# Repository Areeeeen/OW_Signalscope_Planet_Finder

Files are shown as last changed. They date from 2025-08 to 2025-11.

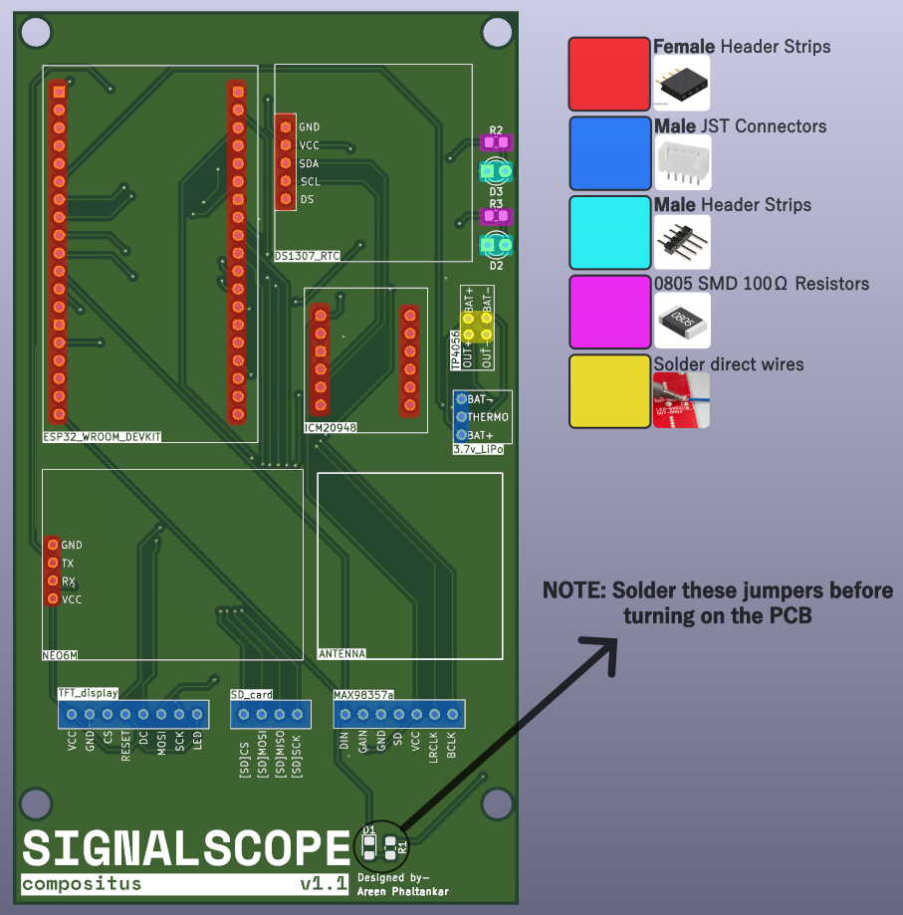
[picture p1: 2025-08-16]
PCB design files/Compositus/v1.1/PCB_assembly_instructions.png

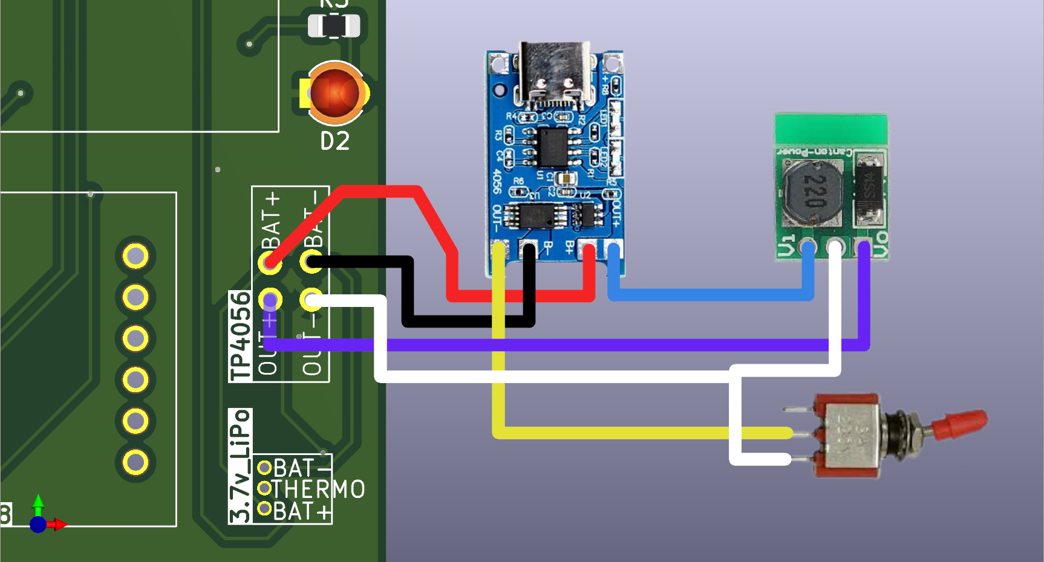
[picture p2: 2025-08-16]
PCB design files/Compositus/general POWER CIRCUIT schematic.png

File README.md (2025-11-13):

# OW_Signalscope_Planet_Finder
An open-source, portable, Outer Wilds 'SignalScope' inspired Planet Finder, based on the ESP32-WROOM (38 pin) microcontroller

refer to this instructables link for instructions on assembly - https://www.instructables.com/Outer-Wilds-Signalscope-Inspired-Planet-Finder/

poster1
display

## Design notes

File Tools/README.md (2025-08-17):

these are Arduino codes which will help in building the signalscope

**i2c_Scanner** - to check which I2C address each I2C module uses, in the case that you use different components than i did

**ICM20948_Calibration** - to find magnetometer and accelerometer offsets of the IMU. (use code when ESP32 and all other compoenents are in their respective places on the device)

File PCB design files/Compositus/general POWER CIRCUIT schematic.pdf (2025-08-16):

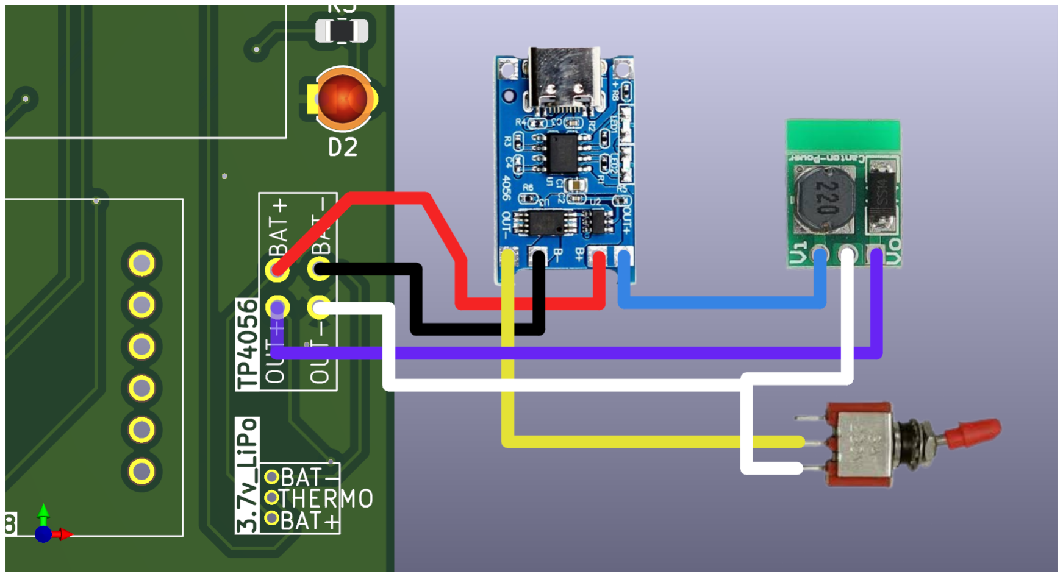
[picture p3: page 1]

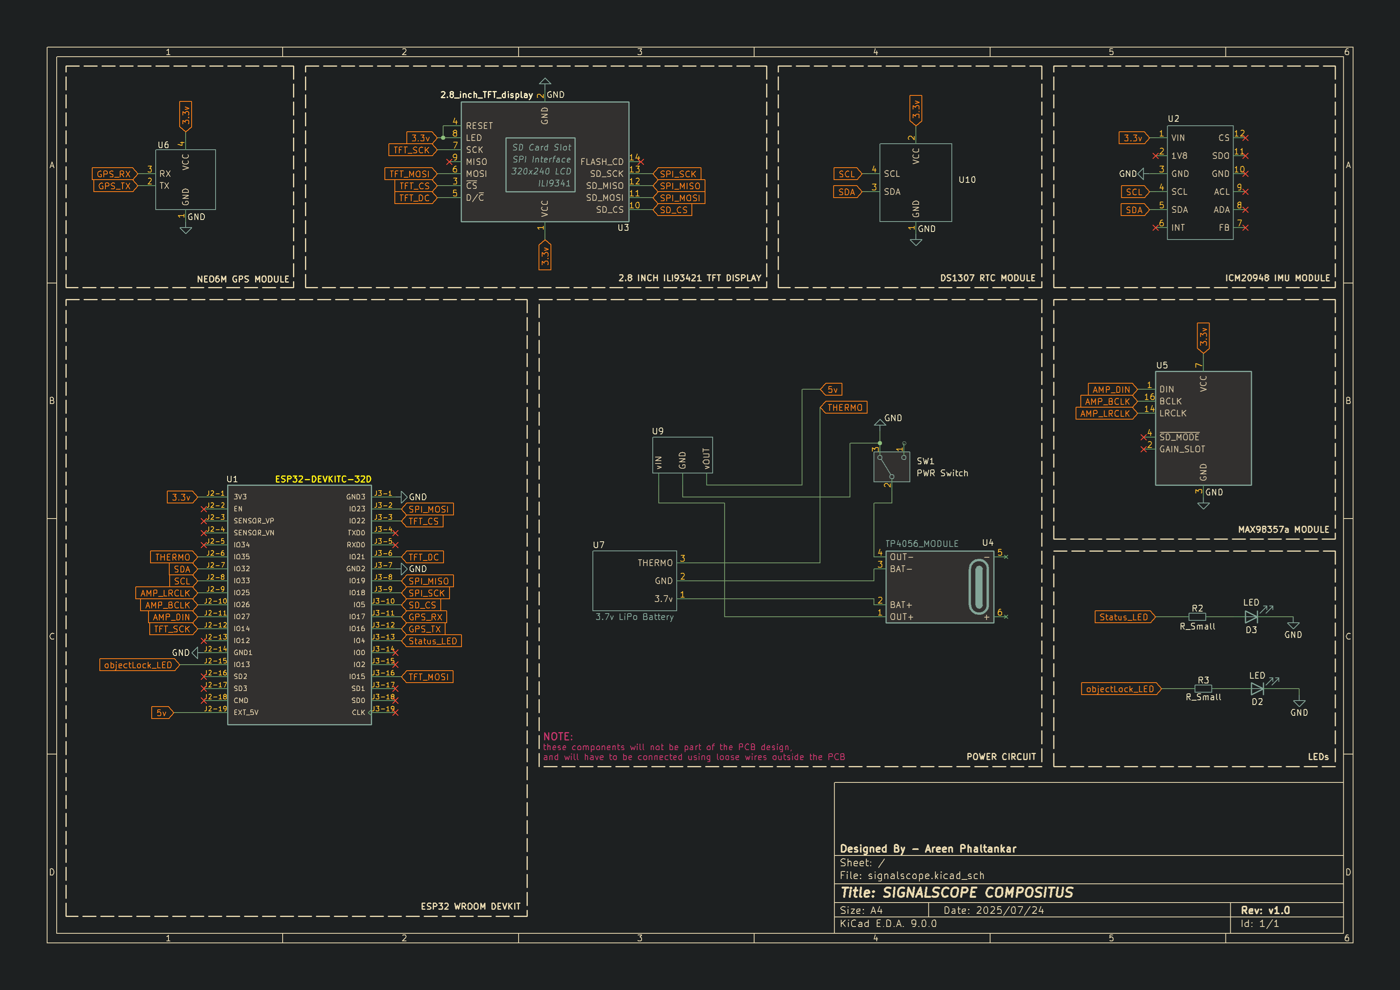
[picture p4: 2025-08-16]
PCB design files/Compositus/v1.1/schematic.png

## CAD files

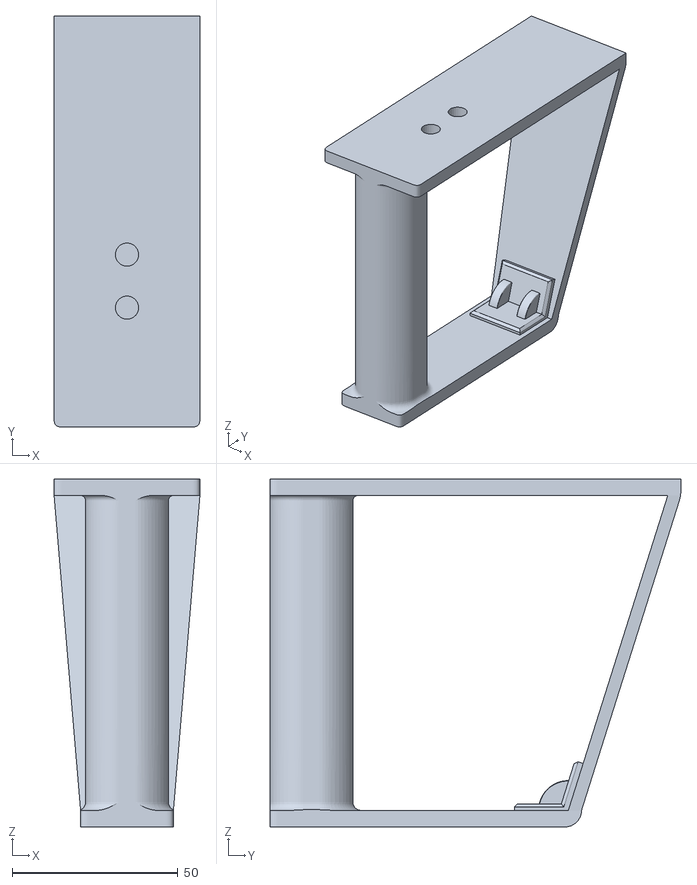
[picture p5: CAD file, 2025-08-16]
3D model files/Handle/Handle_STL_v1.0.stl
44.0 x 124.0 x 105.0

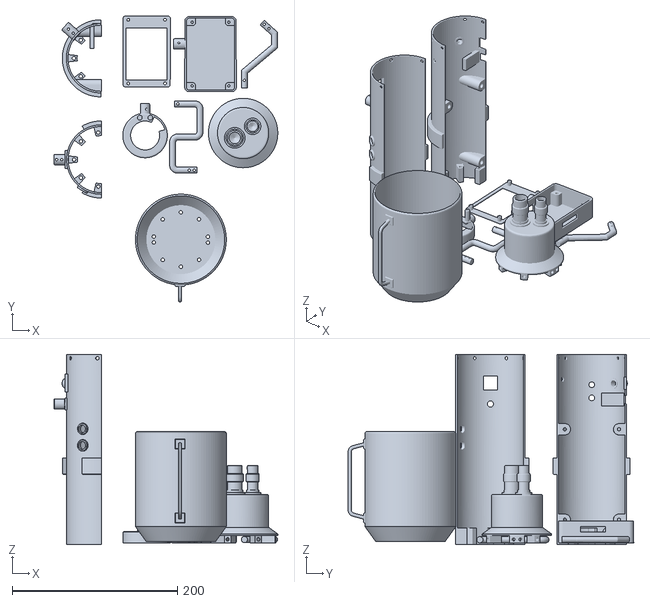
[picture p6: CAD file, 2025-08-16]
3D model files/v1.0/Signalscope_STL_v1.0.stl
270.7 x 346.1 x 230.0

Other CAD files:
3D model files/Handle/Handle_FUSION_v1.0.f3d

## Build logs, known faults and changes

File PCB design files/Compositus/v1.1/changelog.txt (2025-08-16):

- changed pitch and hole diameter of battery connector footprint to 2.54 and 1.5 respectively
- so that it can be easily used with 2.54 pitch JST connector

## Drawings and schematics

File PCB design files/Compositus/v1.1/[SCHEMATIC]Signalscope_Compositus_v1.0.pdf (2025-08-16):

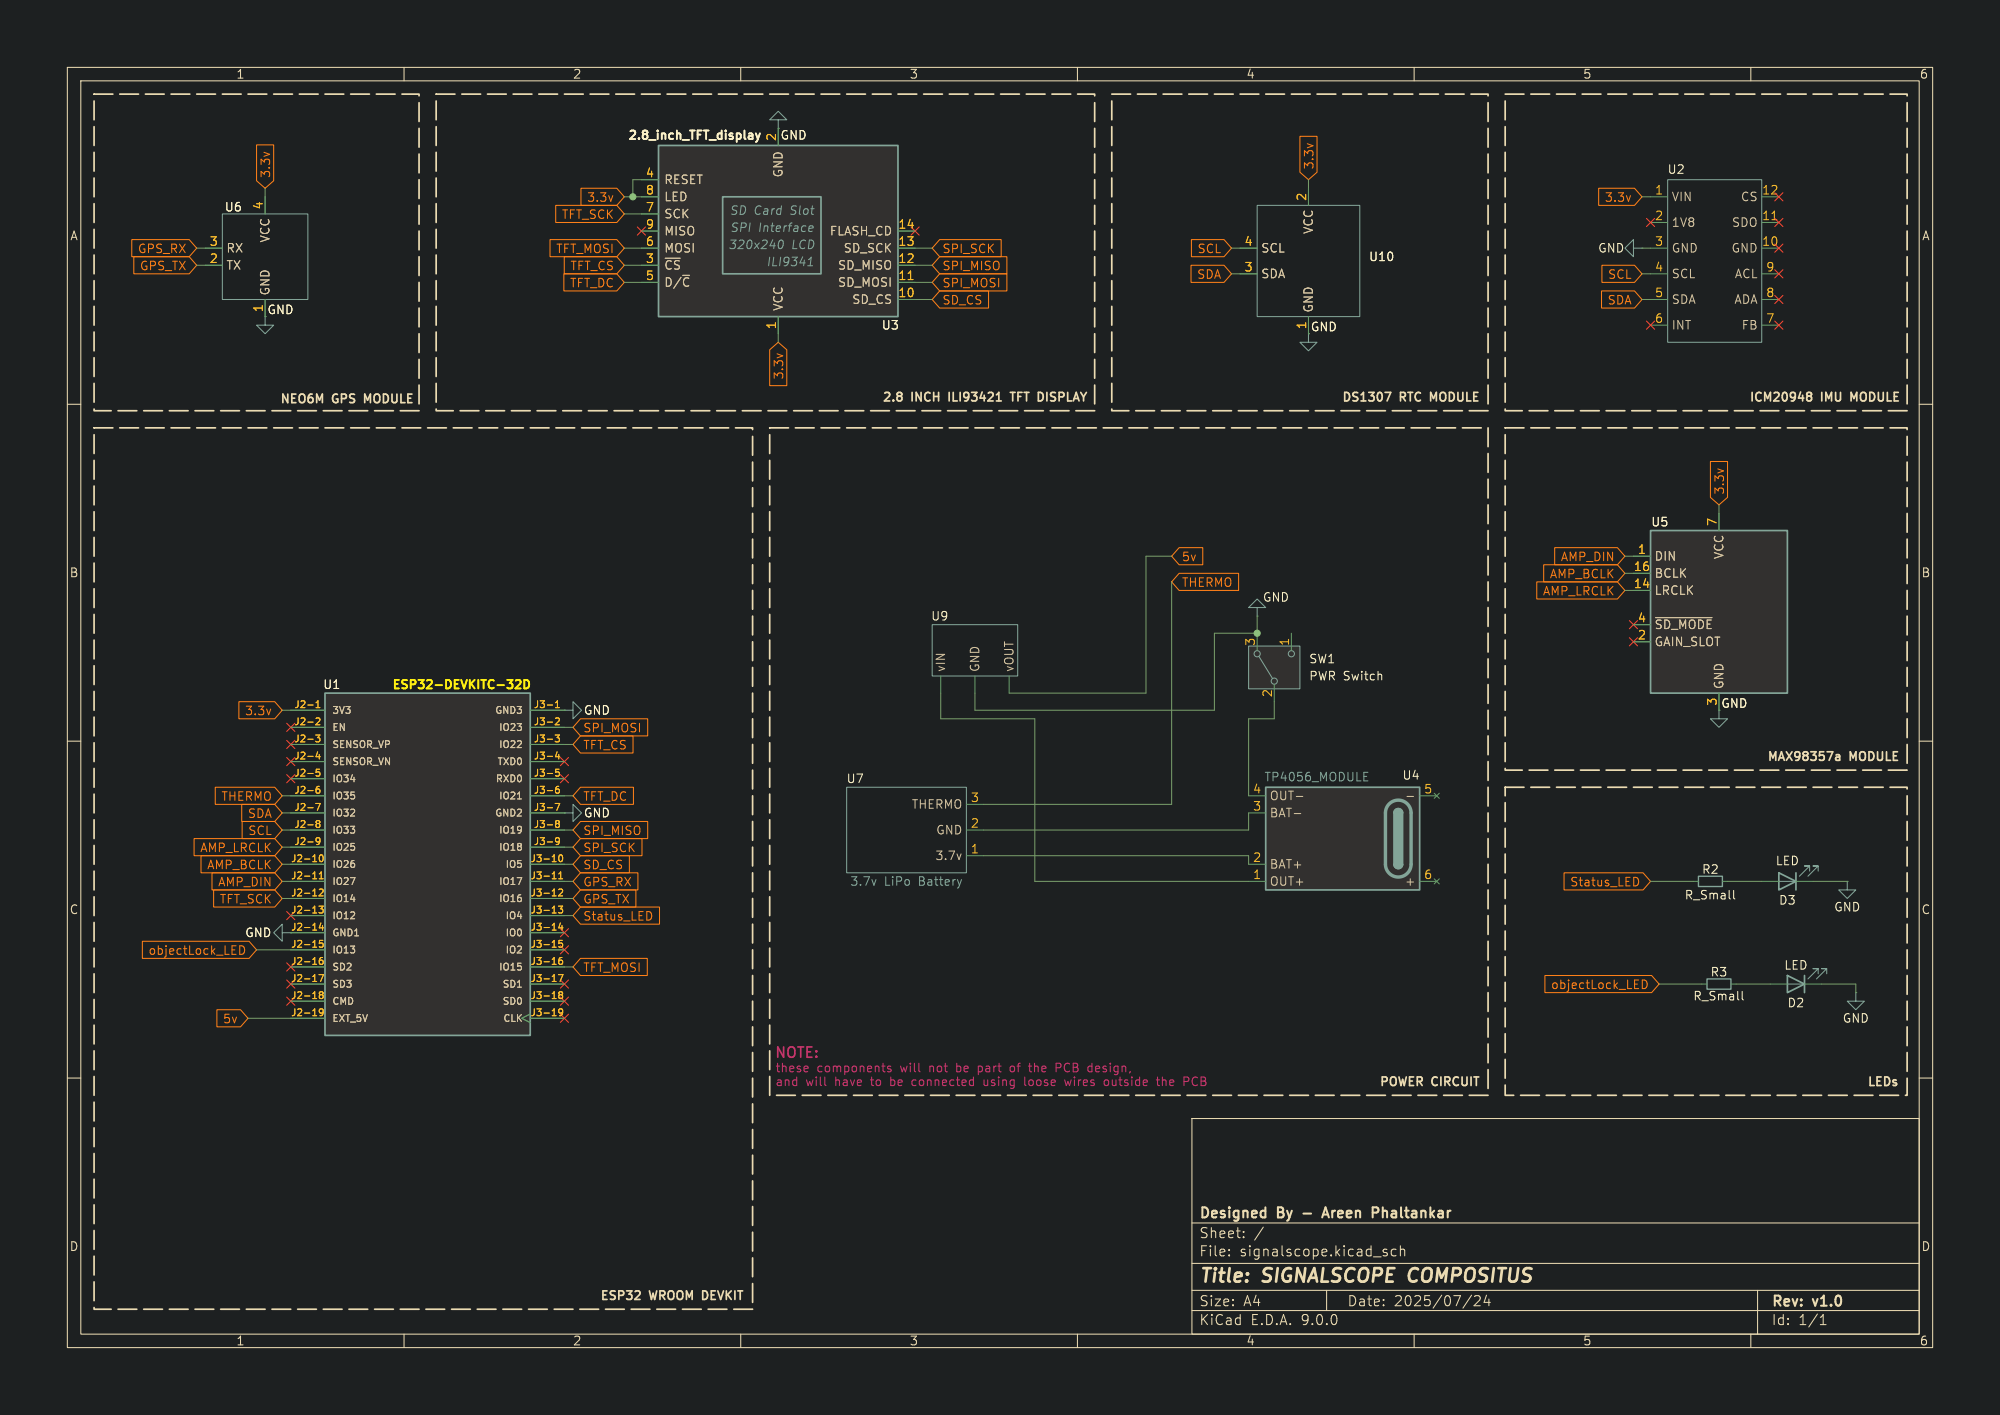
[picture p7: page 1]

2 D/~{C} 5 ~{CS} 3 MOSI 6 MISO 9 SCK 7

3.7v LiPo Battery THERMO 3 GND 2

Id: 1/1 Title: SIGNALSCOPE COMPOSITUS

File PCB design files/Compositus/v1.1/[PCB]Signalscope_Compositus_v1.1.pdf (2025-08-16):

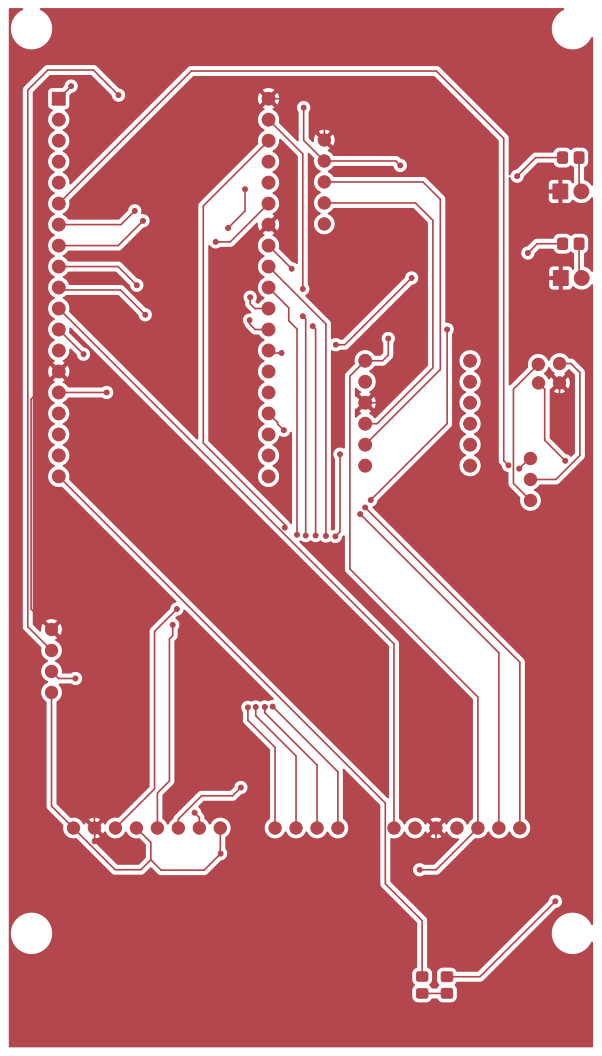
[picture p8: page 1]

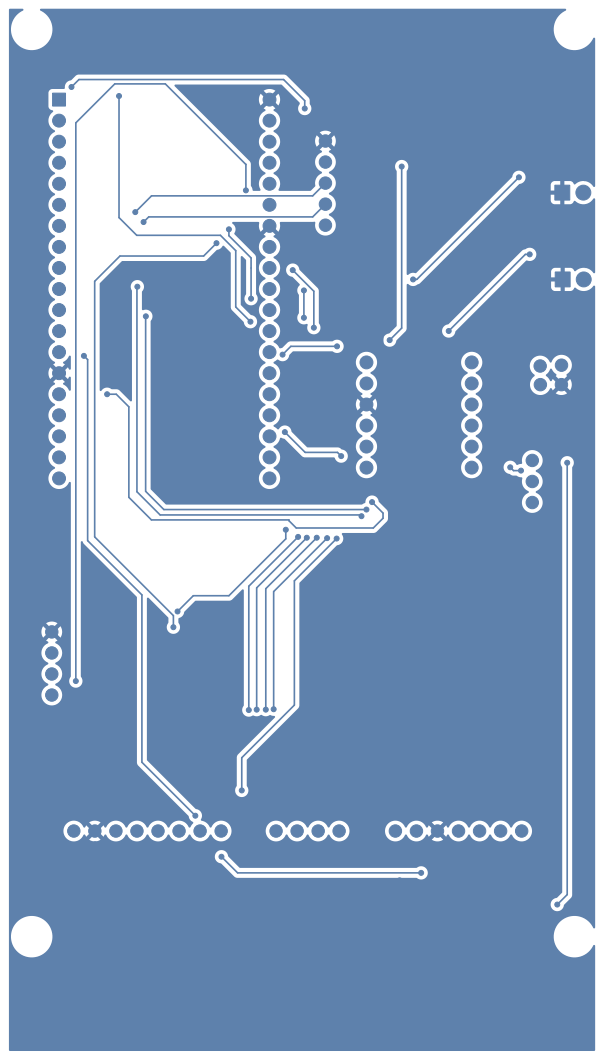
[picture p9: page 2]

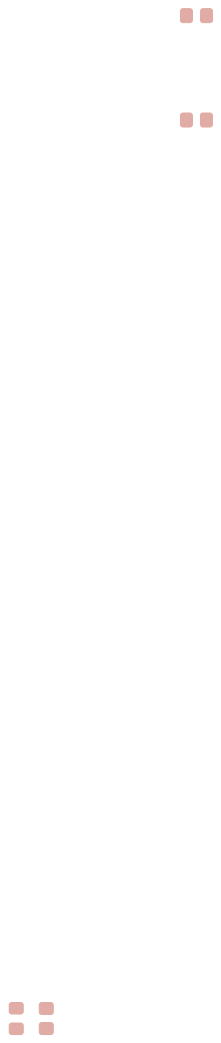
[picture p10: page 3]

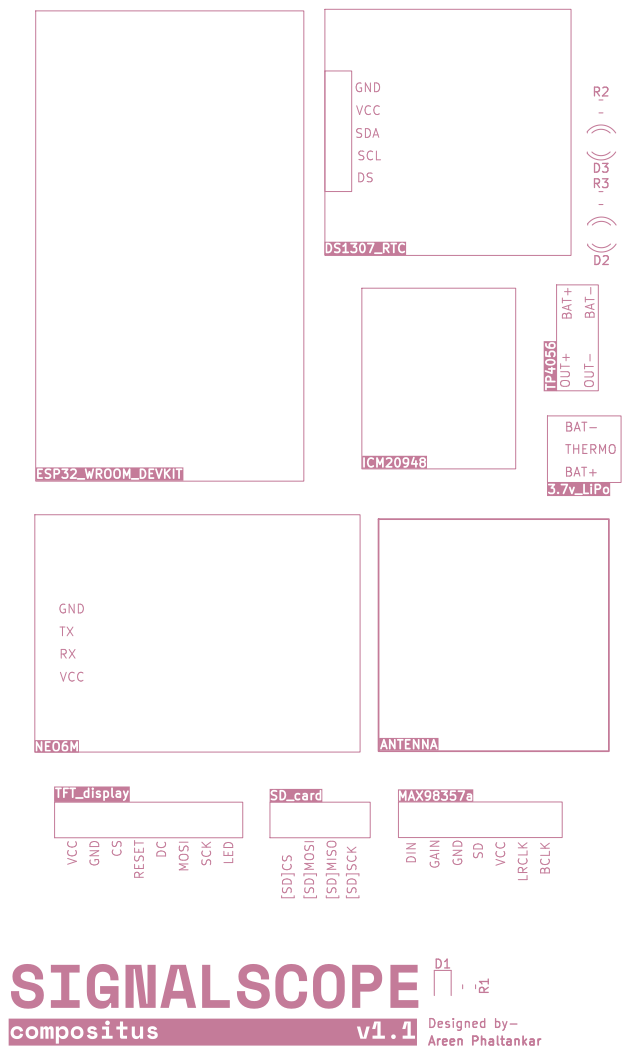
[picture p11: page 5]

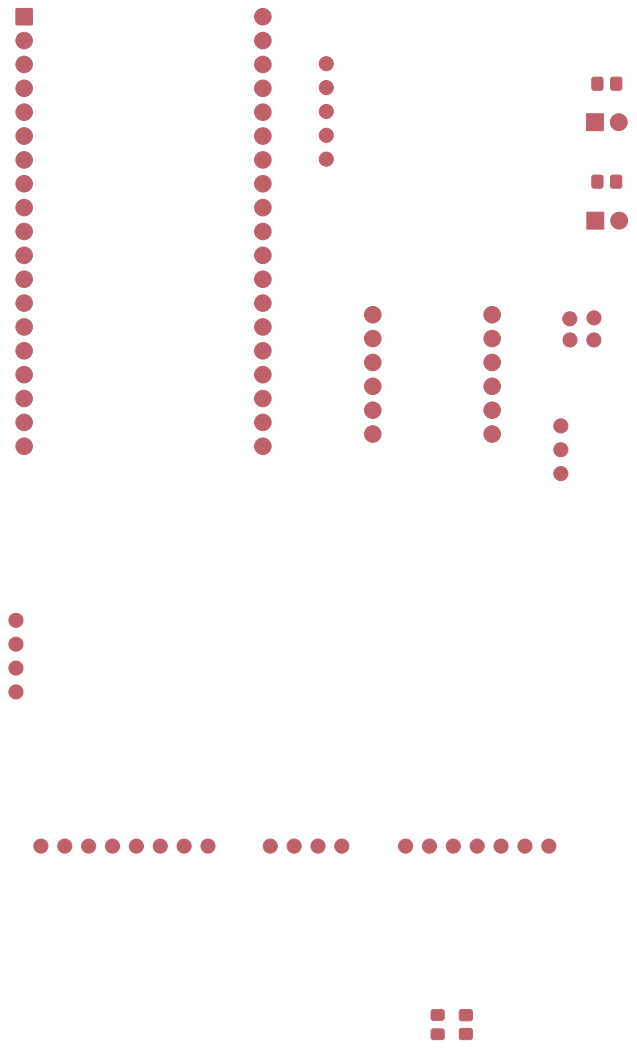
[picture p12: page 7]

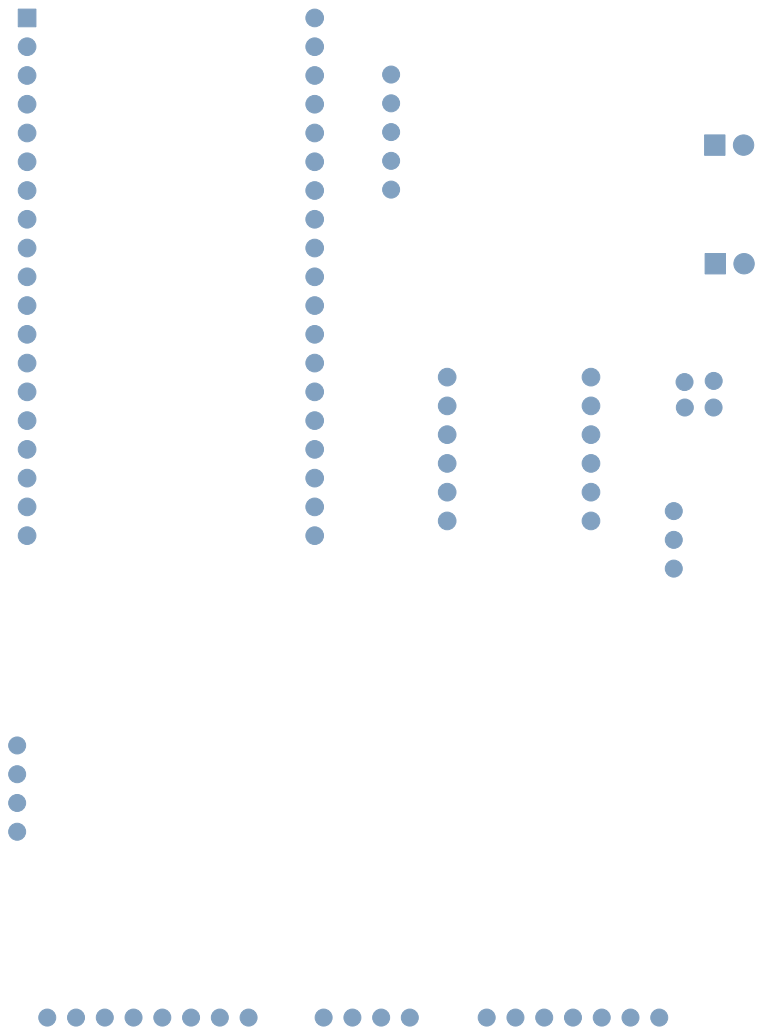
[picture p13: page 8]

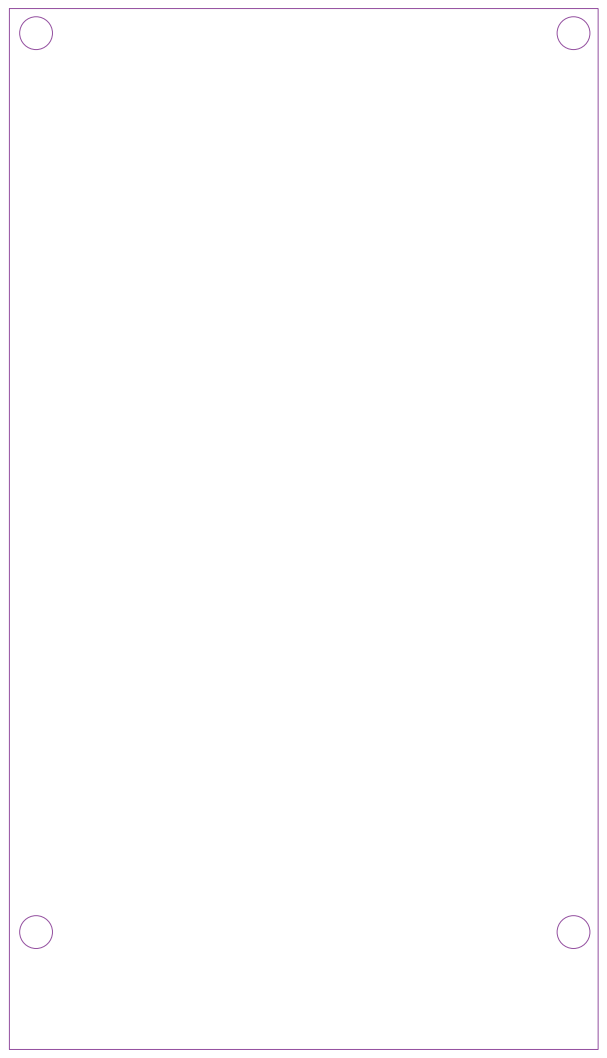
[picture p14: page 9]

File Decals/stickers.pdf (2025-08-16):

# WILDS [1]

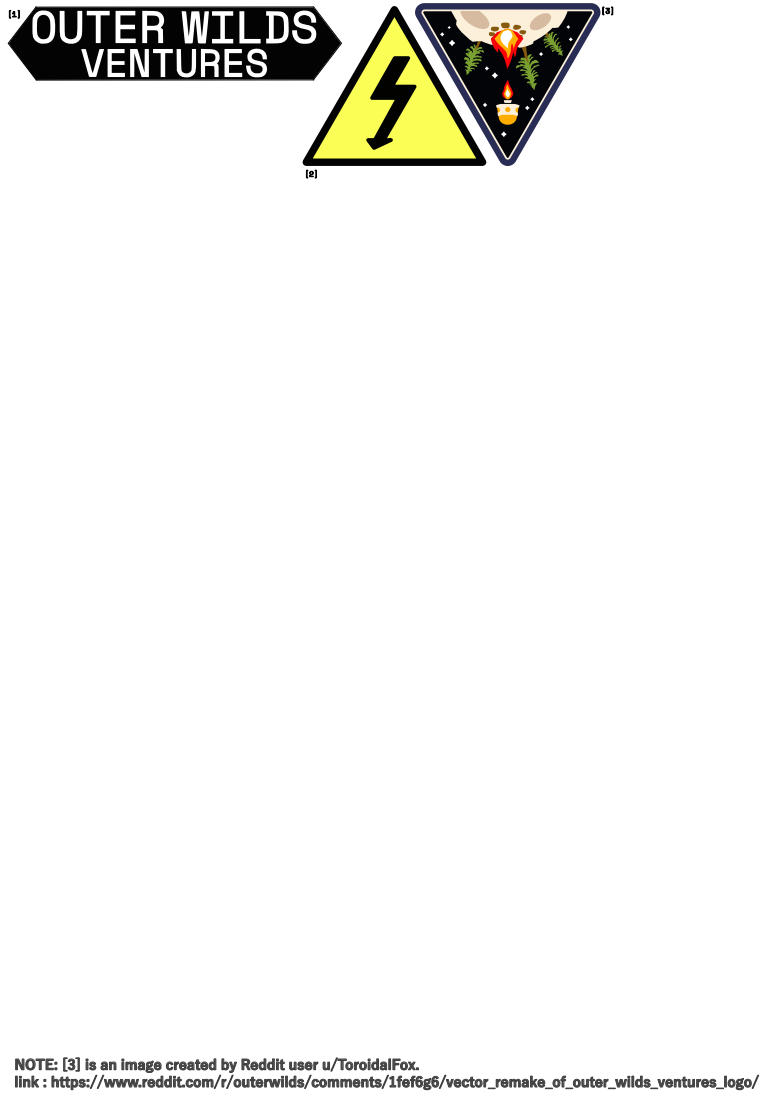
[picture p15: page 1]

NOTE: [3] is an image created by Reddit user u/ToroidalFox.
link : https://www.reddit.com/r/outerwilds/comments/1fef6g6/vector̲remake̲of̲outer̲wilds̲ventures̲logo/

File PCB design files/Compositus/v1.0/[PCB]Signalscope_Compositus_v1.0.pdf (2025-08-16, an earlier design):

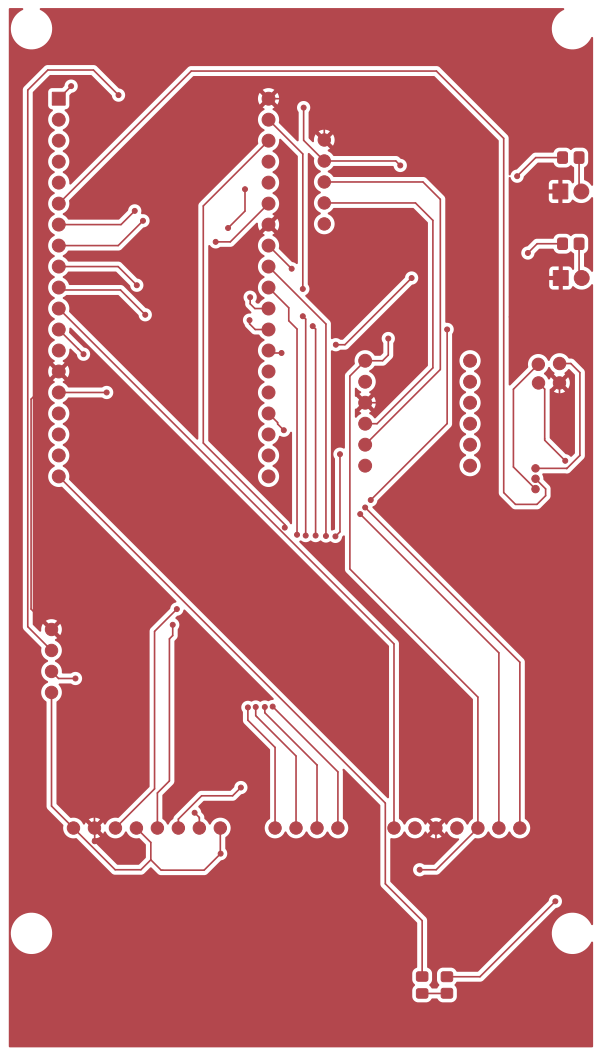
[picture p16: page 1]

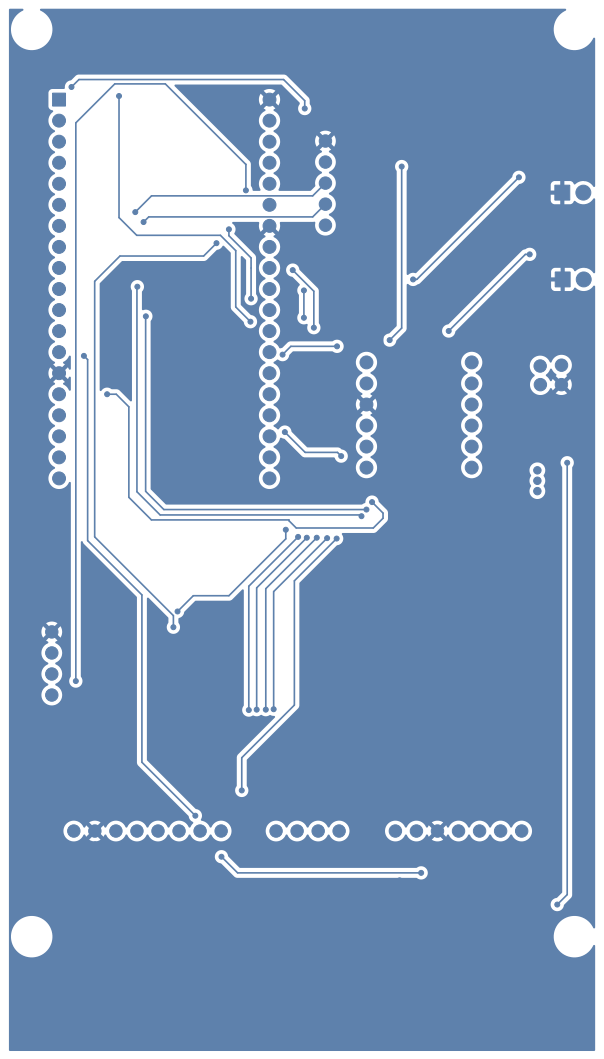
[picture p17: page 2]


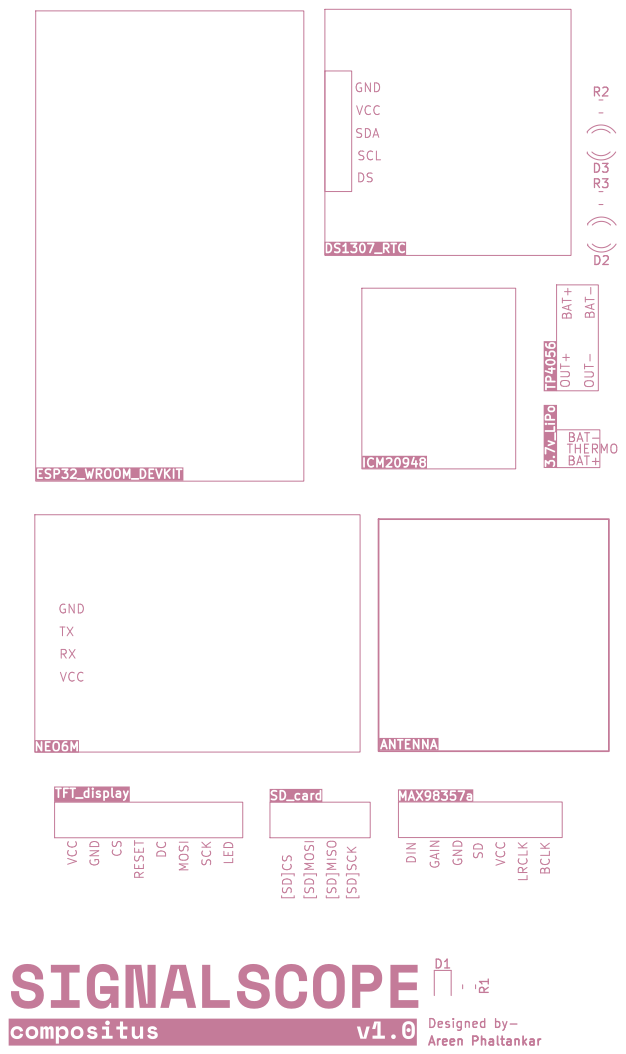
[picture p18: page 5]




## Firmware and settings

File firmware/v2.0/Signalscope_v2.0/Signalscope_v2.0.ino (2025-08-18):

// Signalscope_v2.0
// Made By - Areen Phaltankar

#include <Wire.h>
#include <ICM20948_WE.h>
#include <RTClib.h>
#include <TFT_eSPI.h>
#include <FS.h>
#include <WiFi.h>
#include <HTTPClient.h>
#include <ArduinoJson.h>
#include <AudioFileSourceSD.h>
#include <AudioGeneratorWAV.h>
#include <AudioOutputI2S.h>
#include <AudioFileSourceBuffer.h>
#include <TinyGPS++.h>
#include <SPI.h>
#include <SD.h>
#include <PNGdec.h>

#define ASTRONOMY_ENGINE_WHOLE_SECOND   // ESP32: use 1-second resolution
#include "astronomy.h"                  // keep astronomy.c beside the sketch, compiled as a separate file
#include "loading.h" // The loading screen image data in flash array

const char* ssid = "YOUR_WIFI_NAME";
const char* password = "YOUR_WIFI_PASSWORD";

double latitude = //YOUR_LONGITUDE;
double longitude = //YOUR_LONGITUDE;

astro_time_t astroTime;                 // current time for Astronomy Engine
astro_observer_t observer = { 0, 0, 0}; // lat, lon, elevation meters (set after GPS / fallback)

struct Planet {              // Define a struct to hold planet data
  const char* name;
  const char* music;
  float dec;
  float RA;
  float Az;                  // data will be added by the code for the Azimuth and Altitude
  float Alt;
  float offset;
  float distanceAU;
};

Planet planets[] = {                                    
  {"Mercury", "/Mercury.wav"},
  {"Venus",   "/Venus.wav"},
  {"Mars",    "/Mars.wav"},
  {"Jupiter", "/Jupiter.wav"},         
  {"Saturn",  "/Saturn.wav"},
  {"Uranus",  "/Uranus.wav"},
  {"Neptune", "/Neptune.wav"}
};

PNG png;
#define MAX_IMAGE_WIDTH 240
int16_t xpos = 0;
int16_t ypos = 0;

TaskHandle_t TaskCore0Handle;
TaskHandle_t AudioTaskHandle;

ICM20948_WE myIMU = ICM20948_WE(0x69);
const float magX_offset = -21.902;
const float magY_offset = -12.483;
const float magZ_offset = 27.059;
volatile float altitude_deg;
volatile float azimuth_deg;
float closestOffset;
String closestPlanet;
float closestDistance;
volatile bool imuDataReady = false;

RTC_DS1307 rtc;
#define IST_OFFSET_SECONDS 19800
#define NTP_SERVER "pool.ntp.org"

bool wifiConnected = false;

HardwareSerial gpsSerial(2); // Serial2 for GPS
TinyGPSPlus gps;

TFT_eSPI tft = TFT_eSPI();
TFT_eSprite sprite = TFT_eSprite(&tft);  // Framebuffer sprite
uint8_t radius       = 60; // Arc outer radius
uint8_t thickness    = 4;
uint8_t inner_radius = radius - thickness;
uint16_t LEFTstart_angle = 0;
uint16_t LEFTend_angle   = 180;
uint16_t RIGHTstart_angle = 180;
uint16_t RIGHTend_angle   = 0;
bool arc_end = true;
int centerX = 120;
int centerY = 160;

unsigned long lastUpdateTime = 0;
const unsigned long updateInterval = 5000;

#define GPS_RX 16
#define GPS_TX 17
#define GPS_BAUD 9600

#define TFT_MOSI 15
#define TFT_SCLK 14
#define TFT_CS   22
#define TFT_DC   21
#define TFT_RST  -1

SPIClass mySPI(VSPI);
#define SD_CS    5
#define SD_SCK   18
#define SD_MISO  19
#define SD_MOSI  23

#define I2S_BCLK 26
#define I2S_LRCK 25
#define I2S_DOUT 27

#define LED_PWR 4
#define LED_LOCKOn 13

AudioGeneratorWAV *wav = nullptr;
AudioFileSourceSD *file = nullptr;
AudioOutputI2S *out = nullptr;
AudioFileSourceBuffer *buff = nullptr;

#define AA_FONT_SMALL "NotoSansBold15"
#define AA_FONT_LARGE "NotoSansBold36"

void pngDraw(PNGDRAW *pDraw) {
  uint16_t lineBuffer[MAX_IMAGE_WIDTH];
  png.getLineAsRGB565(pDraw, lineBuffer, PNG_RGB565_BIG_ENDIAN, 0xffffffff);
  tft.pushImage(xpos, ypos + pDraw->y, pDraw->iWidth, 1, lineBuffer);
}

String currentPlaying = "";
const float offsetThreshold = 20.0;

void handlePlanetAudio() {
  // If offset is too large, stop audio if running
  if (closestOffset > offsetThreshold) {
    if (wav && wav->isRunning()) {
      wav->stop();
      currentPlaying = "";
    }
    return;
  }

  // Find the matching planet to get the file path
  const char* filepath = nullptr;
  for (int i = 0; i < 7; i++) {
    if (String(planets[i].name) == closestPlanet) {
      filepath = planets[i].music;
      break;
    }
  }

  if (filepath == nullptr) return; // No matching file

  // Avoid restarting same track
  if (currentPlaying == String(filepath) && wav && wav->isRunning()) {
    // Update volume based on offset
    float vol = 1.0 - (closestOffset / offsetThreshold);
    vol = constrain(vol, 0.0, 1.0);
    if (out) out->SetGain(vol);
    return;
  }

  // Stop any current audio
  if (wav && wav->isRunning()) wav->stop();
  if (file) delete file;
  if (buff) delete buff;
  if (wav) delete wav;
  if (out) delete out;

  // Prepare new file and playback
  file = new AudioFileSourceSD(filepath);
  buff = new AudioFileSourceBuffer(file, 8192);
  out = new AudioOutputI2S();
  out->SetPinout(26, 25, 27);  // Replace with your actual I2S pins

  // Set initial volume based on offset
  float volume = 1.0 - (closestOffset / offsetThreshold);
  volume = constrain(volume, 0.0, 1.0);
  out->SetGain(volume);

  wav = new AudioGeneratorWAV();
  if (!wav->begin(buff, out)) {
    Serial.println("Failed to play audio.");
    currentPlaying = "";
  } else {
    Serial.print("Now playing: ");
    Serial.println(filepath);
    currentPlaying = String(filepath);
  }
}

void updateUserLocation() {
  Serial.print("Latitude: ");
  Serial.println(gps.location.lat(), 6);
  latitude = gps.location.lat();

  Serial.print("Longitude: ");
  Serial.println(gps.location.lng(), 6);
  longitude = gps.location.lng();
}

void TaskCore0(void *pvParameters) {
  while (true) {
    xyzFloat gValue;
    xyzFloat angle;
    xyzFloat magValue;

    myIMU.readSensor();
    myIMU.getGValues(&gValue);
    myIMU.getMagValues(&magValue);
    myIMU.getAngles(&angle);

    magValue.x -= magX_offset;
    magValue.y -= magY_offset;
    magValue.z -= magZ_offset;

    // Normalize accelerometer vector
    float normAcc = sqrt(gValue.x * gValue.x + gValue.y * gValue.y + gValue.z * gValue.z);
    float ax = gValue.x / normAcc;
    float ay = gValue.y / normAcc;
    float az = gValue.z / normAcc;

    // Compute pitch (altitude) and roll
    float pitch = atan2(-ax, sqrt(ay * ay + az * az)); // radians
    float roll  = atan2(ay, az); // radians

    // Normalize magnetometer vector
    float normMag = sqrt(magValue.x * magValue.x + magValue.y * magValue.y + magValue.z * magValue.z);
    float mx = magValue.x / normMag;
    float my = magValue.y / normMag;
    float mz = magValue.z / normMag;

    // Tilt compensation for magnetometer
    float mx2 = mx * cos(pitch) + mz * sin(pitch);
    float my2 = mx * sin(roll) * sin(pitch) + my * cos(roll) - mz * sin(roll) * cos(pitch);

    // Azimuth (heading), in radians
    float azimuth = atan2(-my2, mx2);
    float azimuth_deg_local = (azimuth * 180.0 / PI); 
    if (azimuth_deg_local < 0) azimuth_deg += 360.0; // Normalize to 0-360

    float altitude_deg_local = -(pitch * 180.0 / PI);

    azimuth_deg = azimuth_deg_local;
    altitude_deg = altitude_deg_local;
    imuDataReady = true;

    vTaskDelay(50 / portTICK_PERIOD_MS);  // run at ~20Hz
  }
}

void TaskAudio(void *pvParameters) {
  while (true) {
    handlePlanetAudio();  // Adjust volume or switch track if needed

    if (wav && wav->isRunning()) {
      wav->loop();  // Keep audio playing
    } else {
      vTaskDelay(10 / portTICK_PERIOD_MS);  // Light sleep
    }
  }
}

int hack;

void findOffsets() {
  for (int i = 0; i < 7; i++) {
  Planet& target = planets[i];
  float az_rad = azimuth_deg * PI / 180.0;
  float alt_rad = altitude_deg * PI / 180.0;

  // Convert to 3D unit vector
  float dx = cos(alt_rad) * sin(az_rad);
  float dy = cos(alt_rad) * cos(az_rad);
  float dz = sin(alt_rad);

  // Convert planet azimuth & altitude to radians
  float p_az_rad = target.Az * PI / 180.0;
  float p_alt_rad = target.Alt * PI / 180.0;

  // Convert to 3D unit vector
  float pdx = cos(p_alt_rad) * sin(p_az_rad);
  float pdy = cos(p_alt_rad) * cos(p_az_rad);
  float pdz = sin(p_alt_rad);

  // Dot product
  float dot = dx*pdx + dy*pdy + dz*pdz;
  dot = constrain(dot, -1.0, 1.0); // Prevent acos domain errors

  float angleBetween = acos(dot) * 180.0 / PI;

  target.offset = angleBetween;
  }
  //Serial.printf("Running on core: %d\n", xPortGetCoreID());
}

void closestBody() {
  closestOffset = planets[0].offset;
  for (int i = 1; i < 7; i++) {
    if (planets[i].offset < closestOffset) {
      closestOffset = planets[i].offset;
      closestPlanet = planets[i].name;
      closestDistance = planets[i].distanceAU;
    }
  }
}
// Sync DS1307 from NTP if Wi-Fi is up (else leave RTC as-is)
void updateTime() {
  if (WiFi.status() == WL_CONNECTED) {
    configTime(0, 0, "pool.ntp.org");
    delay(1500);

    struct tm gmt;
    if (getLocalTime(&gmt)) {
      rtc.adjust(DateTime(gmt.tm_year + 1900, gmt.tm_mon + 1, gmt.tm_mday,
                          gmt.tm_hour, gmt.tm_min, gmt.tm_sec));
      Serial.println("RTC updated from NTP.");
    } else {
      Serial.println("NTP time not available; keeping RTC time.");
    }
  } else {
    Serial.println("Wi-Fi down; using RTC time.");
  }
}

// Read DS1307 and build astro_time_t
void refreshDateandTime() {
  DateTime now = rtc.now();
  astroTime = Astronomy_MakeTime(now.year(), now.month(), now.day(),
                                 now.hour(), now.minute(), (double)now.second());
  // (optional) show the time you’re feeding AE:
  astro_utc_t utc = Astronomy_UtcFromTime(astroTime);
  Serial.printf("UTC: %04d-%02d-%02d %02d:%02d:%02d\n",
                utc.year, utc.month, utc.day, utc.hour, utc.minute, (int)utc.second);
}

// map Planet.name -> astro_body_t
static bool nameToBody(const char* n, astro_body_t &body) {
  if      (!strcmp(n,"Mercury")) body = BODY_MERCURY;
  else if (!strcmp(n,"Venus"))   body = BODY_VENUS;
  else if (!strcmp(n,"Mars"))    body = BODY_MARS;
  else if (!strcmp(n,"Jupiter")) body = BODY_JUPITER;
  else if (!strcmp(n,"Saturn"))  body = BODY_SATURN;
  else if (!strcmp(n,"Uranus"))  body = BODY_URANUS;
  else if (!strcmp(n,"Neptune")) body = BODY_NEPTUNE;
  else return false;
  return true;
}

// Updates a single planet's RA/Dec, Az/Alt, and Earth distance (AU)
void refreshAzAlt(Planet& p) {
  astro_body_t body;
  if (!nameToBody(p.name, body)) return;

  // apparent RA/Dec at observer’s location (equator-of-date, with aberration)
  astro_equatorial_t equ = Astronomy_Equator(body, &astroTime, observer,
                                             EQUATOR_OF_DATE, ABERRATION);
  // store RA/Dec for your struct (degrees)
  p.RA  = equ.ra * 15.0;                // RA hours -> degrees
  p.dec = equ.dec;

  // convert to horizon (Az/Alt) for this observer
  astro_horizon_t horiz = Astronomy_Horizon(&astroTime, observer,
                                            equ.ra, equ.dec, REFRACTION_NORMAL);
  p.Az  = horiz.azimuth;
  p.Alt = horiz.altitude;

  // geocentric distance in AU: vector(body) - vector(Earth) in heliocentric coords
  astro_vector_t vPlanet = Astronomy_HelioVector(body, astroTime);       // by value
  astro_vector_t vEarth  = Astronomy_HelioVector(BODY_EARTH, astroTime); // by value
  double dx = vPlanet.x - vEarth.x;
  double dy = vPlanet.y - vEarth.y;
  double dz = vPlanet.z - vEarth.z;
  p.distanceAU = sqrt(dx*dx + dy*dy + dz*dz);

  // debug print
  Serial.printf("%s  RA: %.3f°  Dec: %.3f°  Az: %.3f°  Alt: %.3f°  Dist: %.3f AU\n",
                p.name, p.RA, p.dec, p.Az, p.Alt, p.distanceAU);
}

// refresh all planets in your array
void refreshPlanetsData() {
  for (int i = 0; i < (int)(sizeof(planets)/sizeof(planets[0])); ++i) {
    refreshAzAlt(planets[i]);
  }
}


void updateDisplay() {
  sprite.fillSprite(TFT_BLACK);
  sprite.setTextFont(4);
  tft.loadFont(AA_FONT_SMALL);
  sprite.loadFont(AA_FONT_SMALL);
  sprite.setTextColor(TFT_WHITE, TFT_BLACK); 
  sprite.drawString("Source:", 82, 220);
  sprite.drawString("Distance:", 68, 255);

  if (closestOffset <= 4) {
    sprite.drawSmoothArc(centerX, 100, radius, inner_radius, LEFTstart_angle, LEFTend_angle, TFT_BLUE, TFT_BLACK, arc_end);
    sprite.drawSmoothArc(centerX, 100, radius, inner_radius, RIGHTstart_angle, RIGHTend_angle, TFT_BLUE, TFT_BLACK, arc_end);

    // Draw closest planet name below the semicircles
    sprite.setTextColor(TFT_WHITE, TFT_BLACK);
    sprite.setTextDatum(MC_DATUM);  // Center align
    //sprite.setFreeFont(FSSB18);     // Optional: you can choose other fonts, or comment this if not using free fonts
    sprite.drawString(closestPlanet, 175, 220); // Adjust Y for spacing
    sprite.drawFloat(closestDistance, 2, 160, 255);
    hack = 500;
  } else {
    sprite.drawSmoothArc(centerX - closestOffset, 100, radius, inner_radius, LEFTstart_angle, LEFTend_angle, TFT_GREEN, TFT_BLACK, arc_end);
    sprite.drawSmoothArc(centerX + closestOffset, 100, radius, inner_radius, RIGHTstart_angle, RIGHTend_angle, TFT_GREEN, TFT_BLACK, arc_end);
    hack = 50;
  }

  Serial.println(closestOffset);
  Serial.println(closestPlanet);

  tft.unloadFont();
  sprite.unloadFont();
  sprite.pushSprite(0, 0);
  delay(hack);
}

void setup() {

  pinMode(LED_LOCKOn, OUTPUT);
  pinMode(LED_PWR, OUTPUT);
  digitalWrite(LED_PWR, HIGH); // turn on power LED

  Wire.begin(32, 33); // SDA-32, SCL-33
  Serial.begin(115200);
  gpsSerial.begin(GPS_BAUD, SERIAL_8N1, GPS_RX, GPS_TX);
  
  tft.init();
  tft.setRotation(0);
  int16_t rc = png.openFLASH((uint8_t *)loading, sizeof(loading), pngDraw);
  if (rc == PNG_SUCCESS) {
    Serial.println("Successfully opened png file");
    Serial.printf("image specs: (%d x %d), %d bpp, pixel type: %d\n", 
      png.getWidth(), png.getHeight(), png.getBpp(), png.getPixelType());

    tft.startWrite();
    uint32_t dt = millis();
    png.decode(NULL, 0); // draw it!
    Serial.print(millis() - dt); Serial.println("ms");
    tft.endWrite();
  }

  // Set up sprite the same size as the screen (or smaller, if you want)
  sprite.setColorDepth(8);  // You can use 16 for better color but more memory
  sprite.createSprite(tft.width(), tft.height());

  xTaskCreatePinnedToCore(
    TaskCore0,
    "TaskCore0",
    8192,
    NULL,
    1,
    &TaskCore0Handle,
    1 // Core 0
  );

  xTaskCreatePinnedToCore(
    TaskAudio,
    "TaskAudio",
    4096,
    NULL,
    10,              // High priority (10 is fine for audio)
    &AudioTaskHandle,
    0                // Run on Core 0
  );
  delay(500);

  unsigned long checkGPS = millis();
  while (millis() - checkGPS < 3000) { // Run for 3 seconds
    while (gpsSerial.available() > 0) {
      gps.encode(gpsSerial.read());
    }
  }

  if (gps.location.isValid()) {
    updateUserLocation();
  } else {
    latitude = 18.551464451319365;
    longitude = 73.79048766793403;     // use hard-coded coordinates if there is no GPS fix
  }
  observer.latitude  = latitude;     // degrees north
  observer.longitude = longitude;    // degrees east
  observer.height    = 0.0;          // meters above sea level (set yours if known)
  gpsSerial.end();
  delay(200);

  Serial.println("Connecting to WiFi...");
  WiFi.begin(ssid, password);

  unsigned long startAttemptTime = millis();
  rtc.begin();
  while (WiFi.status() != WL_CONNECTED && millis() - startAttemptTime < 5000) {
    delay(100);
    Serial.print(".");
  }

  if (WiFi.status() == WL_CONNECTED) {
    wifiConnected = true;
    Serial.println("\nWiFi connected. Syncing time...");

    configTime(IST_OFFSET_SECONDS, 0, NTP_SERVER);
    struct tm timeinfo;
    if (getLocalTime(&timeinfo)) {
      DateTime now(
        timeinfo.tm_year + 1900,
        timeinfo.tm_mon + 1,
        timeinfo.tm_mday,
        timeinfo.tm_hour,
        timeinfo.tm_min,
        timeinfo.tm_sec
      );
      rtc.adjust(now);
      Serial.println("RTC updated from NTP.");
    } else {
      Serial.println("Failed to get time from NTP.");
    }
    WiFi.disconnect(true);
    WiFi.mode(WIFI_OFF);
  }

  mySPI.begin(SD_SCK, SD_MISO, SD_MOSI, SD_CS);
  if (!SD.begin(SD_CS, mySPI, 16000000)) {
    Serial.println("SD card initialization failed!");
    while (1);
  } else {
    Serial.println("SD card initialized.");
  }

  out = new AudioOutputI2S();
  out->SetPinout(I2S_BCLK, I2S_LRCK, I2S_DOUT);
  file = new AudioFileSourceSD("/starwars.wav");
  buff = new AudioFileSourceBuffer(file, 8192);  // You can try 4096 or 8192 too
  wav = new AudioGeneratorWAV();

  if(!myIMU.init()){
    Serial.println("ICM20948 does not respond");  //debugging
  } else {
    Serial.println("ICM20948 is connected");
  }

  if(!myIMU.initMagnetometer()){
  Serial.println("Magnetometer does not respond");
  } else {
    Serial.println("Magnetometer is connected");
  }

  Serial.println("Position your ICM20948 flat and don't move it - calibrating..."); //debugging
  delay(1000);
  myIMU.autoOffsets();
  Serial.println("Done!");  //debugging
  
  myIMU.enableAcc(true);
  myIMU.setAccRange(ICM20948_ACC_RANGE_2G);
  myIMU.setAccDLPF(ICM20948_DLPF_6);
  myIMU.setGyrDLPF(ICM20948_DLPF_6);
  myIMU.setTempDLPF(ICM20948_DLPF_6);
  myIMU.setMagOpMode(AK09916_CONT_MODE_20HZ);   
  myIMU.setAccSampleRateDivider(10);

  #ifndef ESP8266
  while (!Serial); // wait for serial port to connect. Needed for native USB
  #endif
    if (!rtc.begin()) {
      Serial.println("Couldn't find RTC");
      Serial.flush();
      while(1) delay(10);
    }

    if (!rtc.isrunning()) {
      Serial.println("RTC is NOT running, let's set the time!");
      // When time needs to be set on a new device, or after a power loss, the
      // following line sets the RTC to the date & time this sketch was compiled
      rtc.adjust(DateTime(F(__DATE__), F(__TIME__)));
      // This line sets the RTC with an explicit date & time, for example to set
      // January 21, 2014 at 3am you would call:
      // rtc.adjust(DateTime(2014, 1, 21, 3, 0, 0));
    }
  tft.fillScreen(TFT_BLACK);
}

void loop() {

  if (imuDataReady) {
    imuDataReady = false;
    Serial.print("Azimuth (deg): ");
    Serial.println(azimuth_deg, 2);
    Serial.print("Altitude (deg): ");
    Serial.println(altitude_deg, 2);

    // Update planet calculations and display
    refreshDateandTime();
    updateDisplay();
    findOffsets();
    closestBody();

    if (millis() - lastUpdateTime >= 3000) {
      lastUpdateTime = millis();
      refreshPlanetsData();
    }
  }
}

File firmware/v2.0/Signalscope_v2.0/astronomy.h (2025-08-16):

/*
    Astronomy Engine for C/C++.
    https://github.com/cosinekitty/astronomy

    MIT License

    Copyright (c) 2019-2025 Don Cross <cosinekitty@gmail.com>

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
    THE SOFTWARE IS PROVIDED "AS IS", WITHOUT WARRANTY OF ANY KIND, EXPRESS OR
    IMPLIED, INCLUDING BUT NOT LIMITED TO THE WARRANTIES OF MERCHANTABILITY,
    FITNESS FOR A PARTICULAR PURPOSE AND NONINFRINGEMENT. IN NO EVENT SHALL THE
    AUTHORS OR COPYRIGHT HOLDERS BE LIABLE FOR ANY CLAIM, DAMAGES OR OTHER
    LIABILITY, WHETHER IN AN ACTION OF CONTRACT, TORT OR OTHERWISE, ARISING FROM,
    OUT OF OR IN CONNECTION WITH THE SOFTWARE OR THE USE OR OTHER DEALINGS IN THE
    SOFTWARE.
*/

#ifndef __ASTRONOMY_H
#define __ASTRONOMY_H

#include <stddef.h>     /* for size_t */

#ifdef __cplusplus
extern "C" {
#endif

/*---------- numeric constants ----------*/

/**
 * \def C_AUDAY
 * @brief The speed of light in AU/day.
 */
#define C_AUDAY     173.1446326846693

/**
 * \def KM_PER_AU
 * @brief The number of kilometers in one astronomical unit (AU).
 */
#define KM_PER_AU   1.4959787069098932e+8

/**
 * \def AU_PER_LY
 * @brief The number of astronomical units per light-year.
 */
#define AU_PER_LY   63241.07708807546

/**
 * \def DEG2RAD
 * @brief The factor to convert degrees to radians = pi/180.
 */
#define DEG2RAD     0.017453292519943296

/**
 * \def HOUR2RAD
 * @brief The factor to convert sidereal hours to radians = pi/12.
 */
#define HOUR2RAD    0.2617993877991494365

/**
 * \def RAD2DEG
 * @brief The factor to convert radians to degrees = 180/pi.
 */
#define RAD2DEG     57.295779513082321

/**
 * \def RAD2HOUR
 * @brief The factor to convert radians to sidereal hours = 12/pi.
 */
#define RAD2HOUR    3.819718634205488

/**
 * \def SUN_RADIUS_KM
 * @brief The mean radius of the Sun's photosphere, expressed in kilometers. The Sun is nearly spherical.
 */
#define SUN_RADIUS_KM               695700.0

/**
 * \def MERCURY_EQUATORIAL_RADIUS_KM
 * @brief The equatorial radius of Mercury, expressed in kilometers.
 */
#define MERCURY_EQUATORIAL_RADIUS_KM    2440.5

/**
 * \def MERCURY_POLAR_RADIUS_KM
 * @brief The polar radius of Mercury, expressed in kilometers.
 */
#define MERCURY_POLAR_RADIUS_KM         2438.3

/**
 * \def VENUS_RADIUS_KM
 * @brief The mean radius of Venus, expressed in kilometers. Venus is nearly spherical.
 */
#define VENUS_RADIUS_KM     6051.8

/**
 * \def EARTH_EQUATORIAL_RADIUS_KM
 * @brief The equatorial radius of the Earth, expressed in kilometers.
 */
#define EARTH_EQUATORIAL_RADIUS_KM  6378.1366

/**
 * \def EARTH_FLATTENING
 * @brief The Earth's polar radius divided by its equatorial radius.
 */
#define EARTH_FLATTENING            0.996647180302104

/**
 * \def EARTH_POLAR_RADIUS_KM
 * @brief The polar radius of the Earth, expressed in kilometers.
 */
#define EARTH_POLAR_RADIUS_KM       (EARTH_EQUATORIAL_RADIUS_KM * EARTH_FLATTENING)

/**
 * \def MOON_EQUATORIAL_RADIUS_KM
 * @brief The equatorial radius of the Moon, expressed in kilometers.
 */
#define MOON_EQUATORIAL_RADIUS_KM   1738.1

/**
 * \def MOON_POLAR_RADIUS_KM
 * @brief The polar radius of the Moon, expressed in kilometers.
 */
#define MOON_POLAR_RADIUS_KM        1736.0

/**
 * \def MARS_EQUATORIAL_RADIUS_KM
 * @brief The equatorial radius of Mars, expressed in kilometers.
 */
#define MARS_EQUATORIAL_RADIUS_KM   3396.2

/**
 * \def MARS_POLAR_RADIUS_KM
 * @brief The polar radius of Mars, expressed in kilometers.
 */
#define MARS_POLAR_RADIUS_KM        3376.2

/*
    Jupiter radius data are nominal values obtained from:
    https://www.iau.org/static/resolutions/IAU2015_English.pdf
    https://nssdc.gsfc.nasa.gov/planetary/factsheet/jupiterfact.html
*/

/**
 * \def JUPITER_EQUATORIAL_RADIUS_KM
 * @brief The equatorial radius of Jupiter, expressed in kilometers.
 */
#define JUPITER_EQUATORIAL_RADIUS_KM    71492.0

/**
 * \def JUPITER_POLAR_RADIUS_KM
 * @brief The polar radius of Jupiter, expressed in kilometers.
 */
#define JUPITER_POLAR_RADIUS_KM         66854.0

/**
 * \def JUPITER_MEAN_RADIUS_KM
 * @brief The volumetric mean radius of Jupiter, expressed in kilometers.
 */
#define JUPITER_MEAN_RADIUS_KM          69911.0

/*
    The radii of Jupiter's four major moons are obtained from:
    https://ssd.jpl.nasa.gov/?sat_phys_par
*/

/**
 * \def IO_RADIUS_KM
 * @brief The mean radius of Jupiter's moon Io, expressed in kilometers.
 */
#define IO_RADIUS_KM            1821.6

/**
 * \def EUROPA_RADIUS_KM
 * @brief The mean radius of Jupiter's moon Europa, expressed in kilometers.
 */
#define EUROPA_RADIUS_KM        1560.8

/**
 * \def GANYMEDE_RADIUS_KM
 * @brief The mean radius of Jupiter's moon Ganymede, expressed in kilometers.
 */
#define GANYMEDE_RADIUS_KM      2631.2

/**
 * \def CALLISTO_RADIUS_KM
 * @brief The mean radius of Jupiter's moon Callisto, expressed in kilometers.
 */
#define CALLISTO_RADIUS_KM      2410.3

/**
 * \def SATURN_EQUATORIAL_RADIUS_KM
 * @brief The equatorial radius of Saturn, expressed in kilometers.
 */
#define SATURN_EQUATORIAL_RADIUS_KM     60268.0

/**
 * \def SATURN_POLAR_RADIUS_KM
 * @brief The polar radius of Saturn, expressed in kilometers.
 */
#define SATURN_POLAR_RADIUS_KM          54364.0

/**
 * \def URANUS_EQUATORIAL_RADIUS_KM
 * @brief The equatorial radius of Uranus, expressed in kilometers.
 */
#define URANUS_EQUATORIAL_RADIUS_KM     25559.0

/**
 * \def URANUS_POLAR_RADIUS_KM
 * @brief The polar radius of Uranus, expressed in kilometers.
 */
#define URANUS_POLAR_RADIUS_KM          24973.0

/**
 * \def NEPTUNE_EQUATORIAL_RADIUS_KM
 * @brief The equatorial radius of Neptune, expressed in kilometers.
 */
#define NEPTUNE_EQUATORIAL_RADIUS_KM    24764.0

/**
 * \def NEPTUNE_POLAR_RADIUS_KM
 * @brief The polar radius of Neptune, expressed in kilometers.
 */
#define NEPTUNE_POLAR_RADIUS_KM         24341.0

/**
 * \def PLUTO_RADIUS_KM
 * @brief The mean radius of Pluto, expressed in kilometers. Pluto is nearly spherical.
 */
#define PLUTO_RADIUS_KM             1188.3


/*---------- types ----------*/
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
